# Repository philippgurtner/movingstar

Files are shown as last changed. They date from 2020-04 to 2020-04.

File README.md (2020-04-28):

# Movingstar
SwissSkills Homework 2020

Dieses Projekt dient als Hausaufgabe für die Vorselektion.
Mein persönliches Ziel ist es, die Schweizermesterschaft mit FOSS (Free Open Source Software) zu bestreiten.

## Toolchain
- [KiCad](https://github.com/KiCad) -> ECAD: Schema & Layout
- Python -> Berechnungen: Stern z.B.

## Hardware

### Lichtsensor & ADC
I(10klx) = 1mA
I(100lx) = 23uA
VCC = 5V
=> R=5k
U(10klx) = I*R = 1mA * 5k = 5V
U(100lx) = I*R = 23uA * 5k = 115mV

### I2C Levelshifter
U104 (Bewegung Sensor) wird mit 2.5V - 3V versorgt. Das I2C Signal bei 2.5V Versorgung genügt dem Microcontroller (U102) nicht für ein logisches 1 (0.7 * VCC = 0.7 * 5V = 3.5V)
So muss das Signal geshiftet werden.
Dies geschieht nach [NXP AN10441](https://www.nxp.com/docs/en/application-note/AN10441.pdf) über die beiden Mosfets Q102 & Q103.

### Programmieren
Als Programmierschnittstelle wird die UPDI Schnittstelle von Atmel verwendet. Diese kommt mit einem Pin aus.

### Stromversorgung
Die Stromversorgung wurde über eine USB-C Buchse vorgesehen. Es stehen dann ca. 5V von einem Handelsüblichen Steckernetzteil zur Verfügung.
Imax ~= 30LED * 3Farben * ca. 20mA = 1.8A
Somit sollte die Quelle auf 2A ausgelegt werden um alle LEDs komplett anzusteuern.
Für die Versorgung von U104 Steht ein 3.3V (oder auch 2.5V) Spannungsregler U101 zur Verfügung.
Der Microcontroller U102 wird nicht mit 3.3V Versorgt, da sonst die Taktfrequenz gesenkt werden muss. Dies wurde zum Enwicklungszeitpunkt noch nicht gemacht, um alle Möglichkeiten der LED (WS2812B-2020) Ansteuerung offen zu halten.

### LED Ansteuerung

Als LED Ansteuerung wurden mehrere Möglichkeiten offen gelassen.
- SPI Interface MOSI an PA1 (R105 bestückt)
- I2C Interface SDA an PA1 (R105 bestückt)
- Waveform Generator Output WO3 an PA3 (R106 bestückt)

### Accelerometer U104

Der Beschleunigungssensor wird über I2C über den Levelshifter betrieben. Die Interruptpins können optional verwendet werden.
Die Interrupt Pins müssten auch über einen Levelshifter betrieben werden um eine Korrekte Funktion beim Microcontroller zu erzeugen.

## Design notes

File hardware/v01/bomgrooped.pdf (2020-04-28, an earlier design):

movingstar

## Homework SwissSkills BOM Philipp Gurtner

Source: | https://github.com/philippgurtner/movingstar
Date: | So 12 Apr 2020 15:06:56
Tool: | Eeschema 5.1.5
Component Count: | 84
Reference | Quantity | Value | Footprint
C101 C102 C103 C104 C105 C113 C112 C111 C110 C109 C118 C117 C116 C115 C114 C123 C122 C121 C120 C119 C131 C130 C129 C128 C127 C136 C135 C134 C133 C132 C108 C126 C125 C106 C107 | 35 | 100n | Capacitor_SMD:C_0603_1608Metric
C124 | 1 | 4.7u | Capacitor_SMD:C_0603_1608Metric
D101 D102 D103 D104 D105 D111 D112 D113 D114 D115 D106 D107 D108 D109 D110 D116 D117 D118 D119 D120 D121 D122 D123 D124 D125 D126 D127 D128 D129 D130 | 30 | WS2812B-2020 | ws2812b-2020:WS2812B-2020
J101 | 1 | USB_C_Receptacle_USB2.0 | usbc_molex:USB_C_Molex_fyang05
J103 J102 | 2 | Conn_01x03 | Connector_PinHeader_2.54mm:PinHeader_1x03_P2.54mm_Vertical
Q101 | 1 | TEMT6200FX01 | Resistor_SMD:R_0805_2012Metric
Q102 Q103 | 2 | NMOS_GSD (BSS138P) | Package_TO_SOT_SMD:SOT-23
R101 | 1 | 5k | Resistor_SMD:R_0603_1608Metric
R103 R104 R102 R108 R107 | 5 | 4.7k | Resistor_SMD:R_0603_1608Metric
R106 R105 | 2 | jumper | Resistor_SMD:R_0603_1608Metric
U101 | 1 | LM3480-3.3 | Package_TO_SOT_SMD:SOT-23
U102 | 1 | ATtiny1616-M | Package_DFN_QFN:VQFN-20-1EP_3x3mm_P0.4mm_EP1.7x1.7mm
U103 | 1 | TASTER | taster_smd:TASTER
U104 | 1 | MMA8453Q | Package_DFN_QFN:QFN-16-1EP_3x3mm_P0.5mm_EP1.7x1.7mm

Page 1

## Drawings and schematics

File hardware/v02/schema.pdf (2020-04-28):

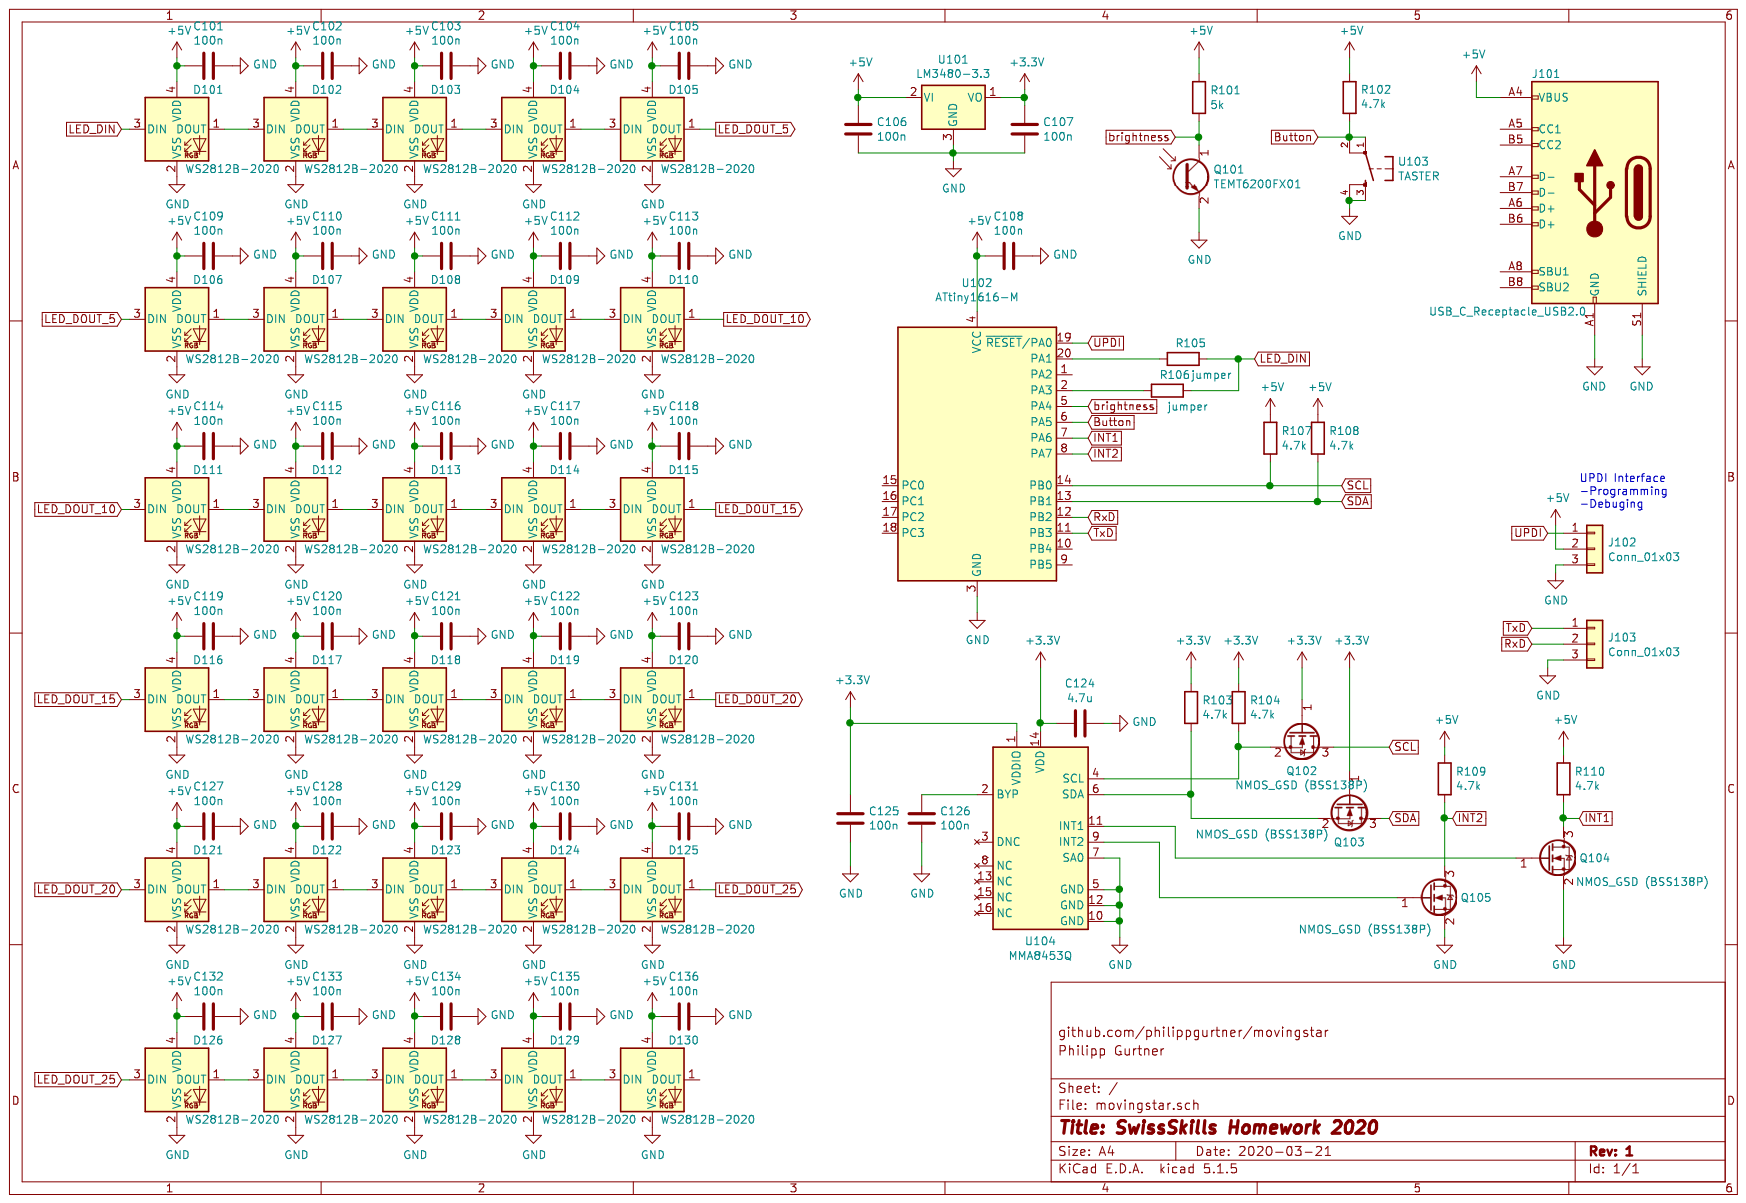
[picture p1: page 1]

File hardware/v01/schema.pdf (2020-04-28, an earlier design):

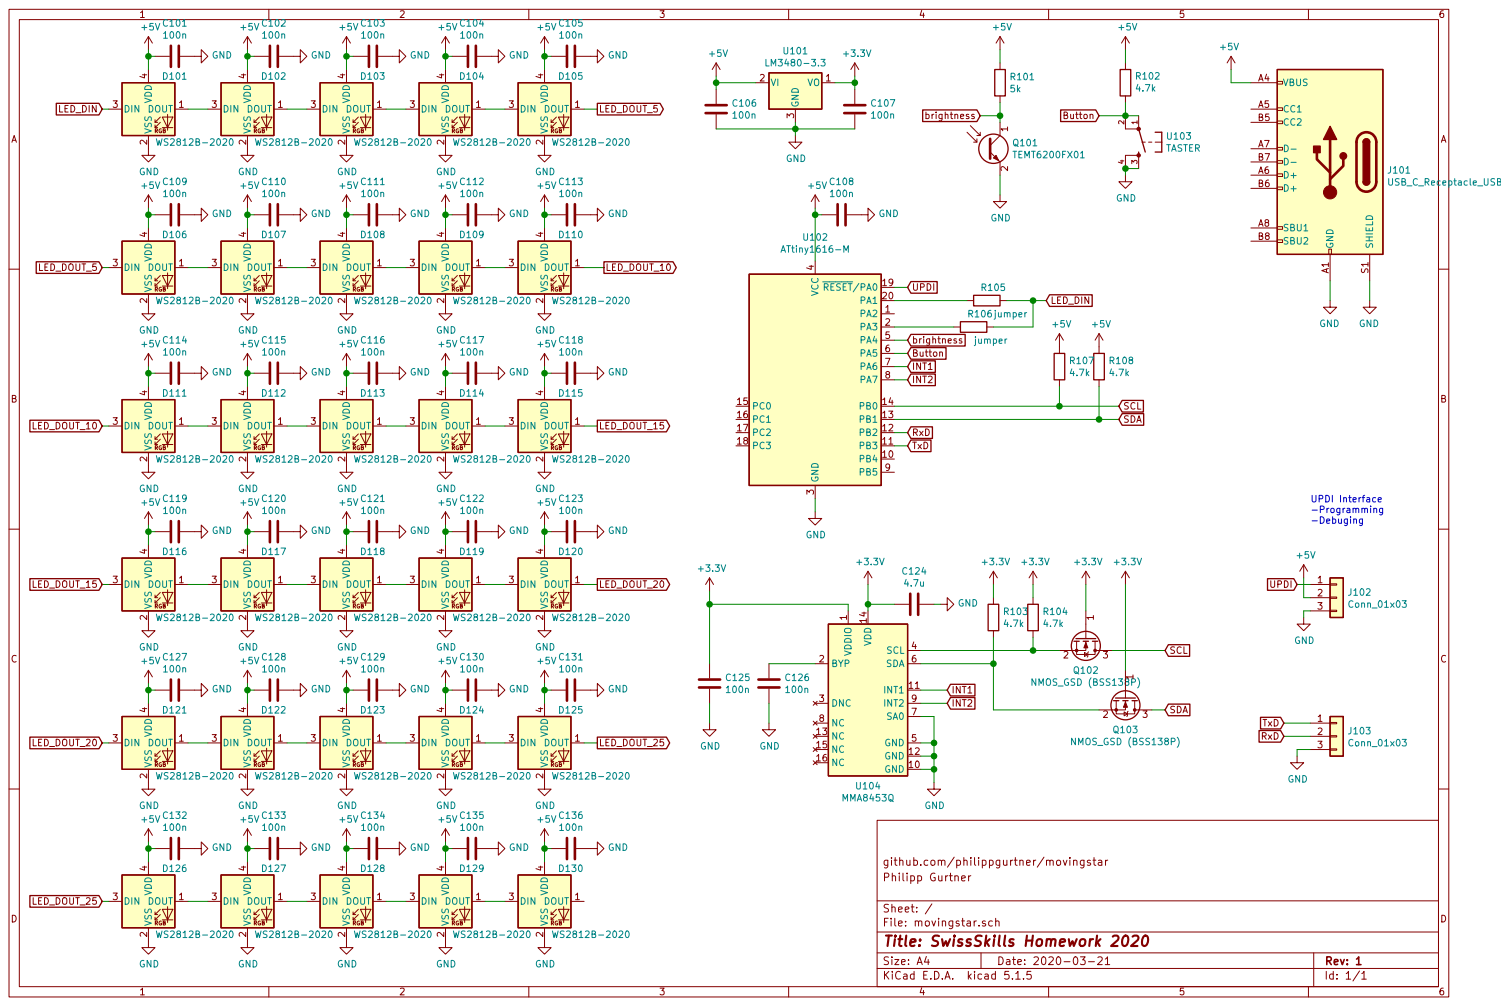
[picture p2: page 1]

1 GND 10 BYP 2 DNC 3 SCL 4 GND 5 SDA 6 SA0 7 NC 8

github.com/philippgurtner/movingstar +5V GND

File: movingstar.sch Sheet: / Philipp Gurtner

Id: 1/1 Title: SwissSkills Homework 2020

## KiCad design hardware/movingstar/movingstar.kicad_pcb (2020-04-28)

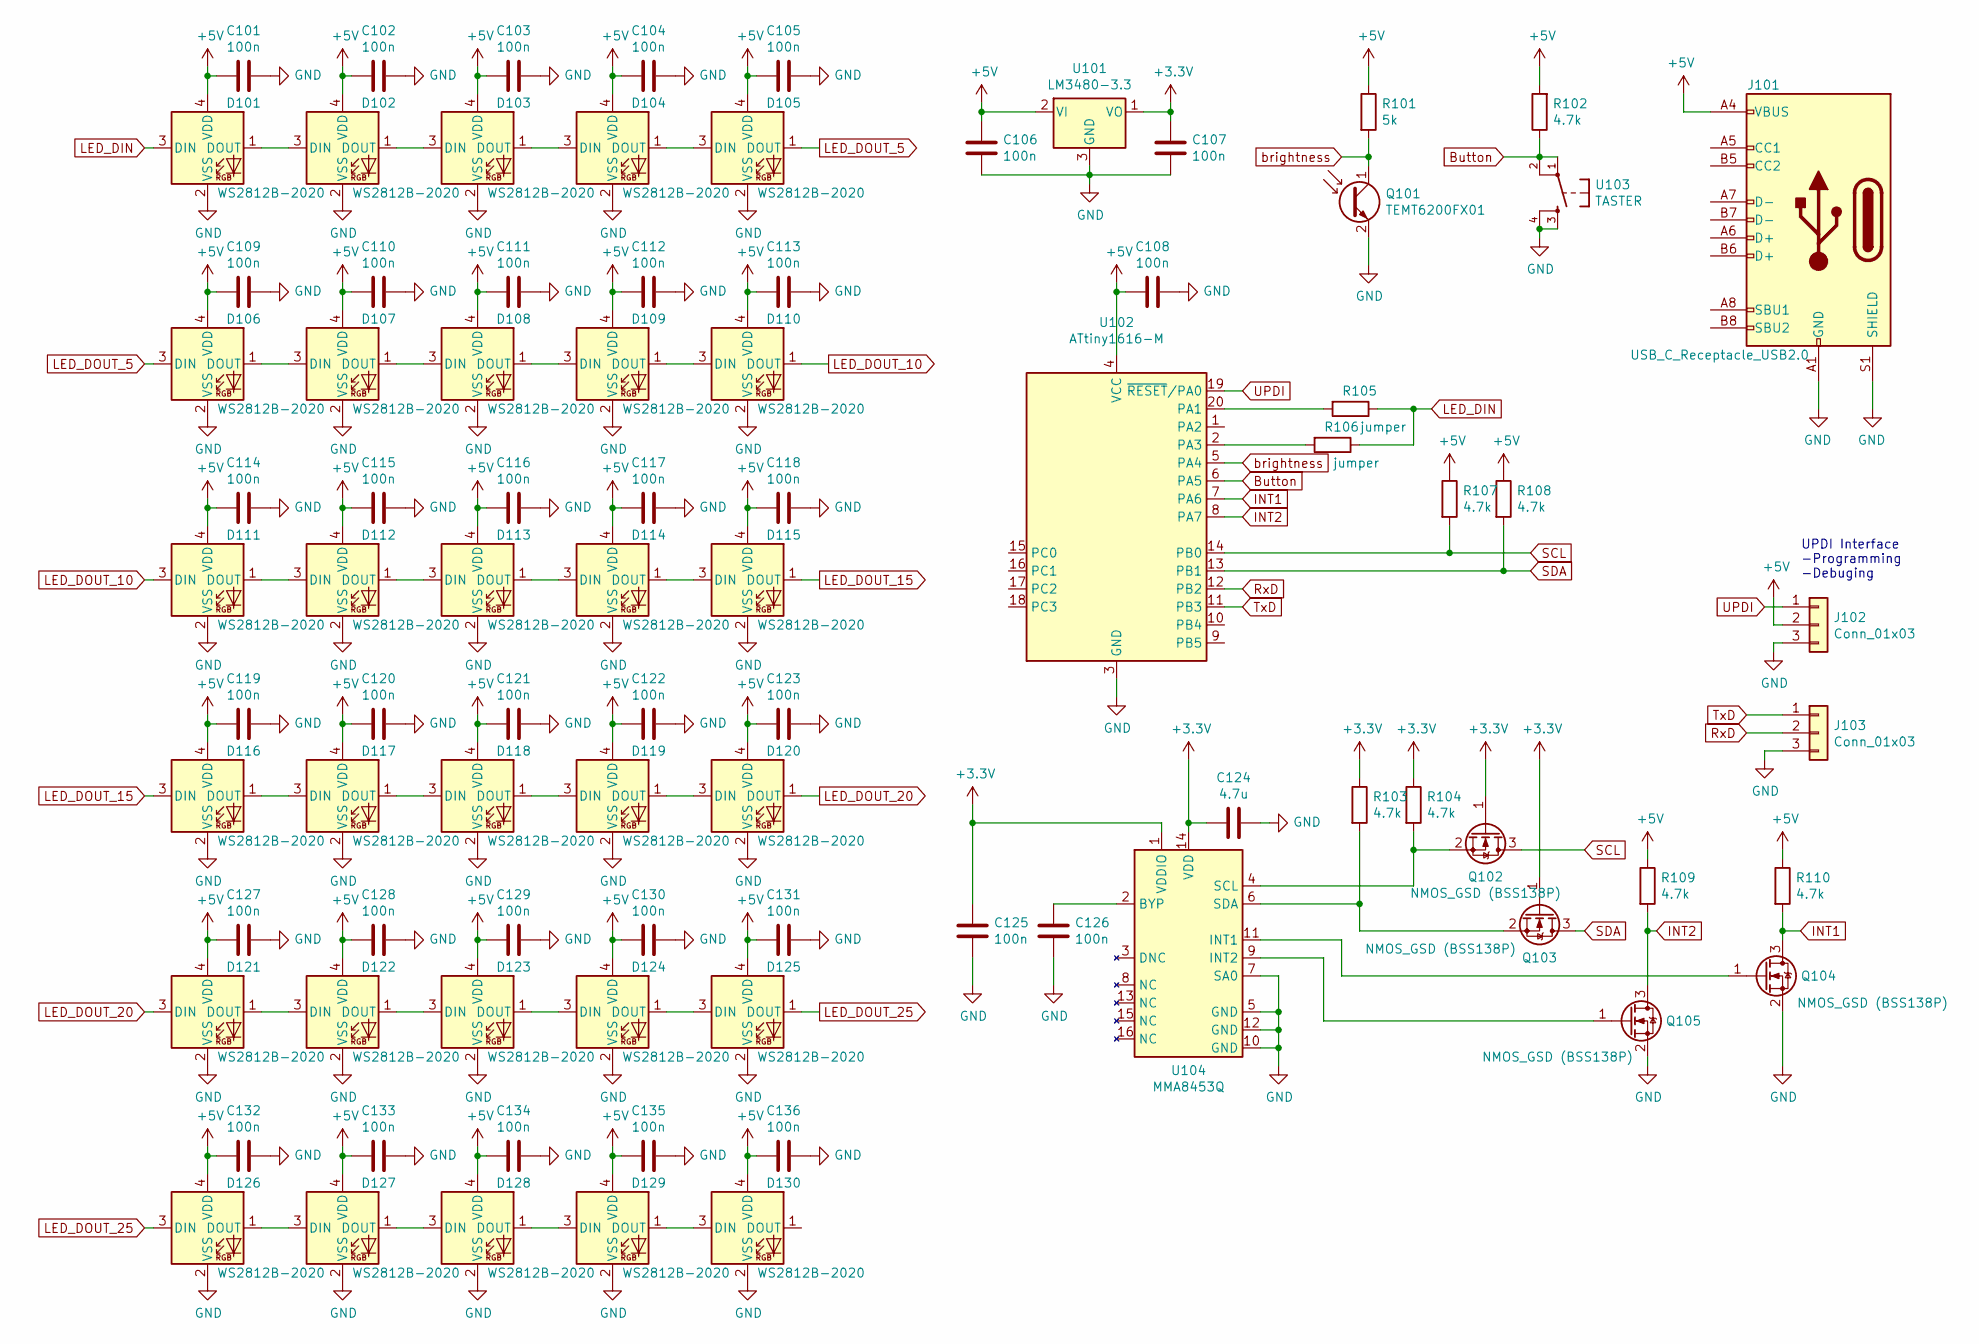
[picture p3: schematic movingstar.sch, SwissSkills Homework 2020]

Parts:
C101, C102, C103, C104, C105, C106, C107, C108, C109, C110, C111, C112, C113, C114, C115, C116, C117, C118, C119, C120, C121, C122, C123, C125, C126, C127, C128, C129, C130, C131, C132, C133, C134, C135, C136: 100n; C_0603_1608Metric
C124: 4.7u; C_0603_1608Metric
D101, D102, D103, D104, D105, D106, D107, D108, D109, D110, D111, D112, D113, D114, D115, D116, D117, D118, D119, D120, D121, D122, D123, D124, D125, D126, D127, D128, D129, D130: WS2812B-2020
J101: USB_C_Receptacle_USB2.0; USB_C_Molex_fyang05
J102, J103: Conn_01x03; PinHeader_1x03_P2.54mm_Vertical
Q101: TEMT6200FX01; R_0805_2012Metric
Q102, Q103, Q104, Q105: NMOS_GSD (BSS138P); SOT-23
R101: 5k; R_0603_1608Metric
R102, R103, R104, R107, R108, R109, R110: 4.7k; R_0603_1608Metric
R105, R106: jumper; R_0603_1608Metric
U101: LM3480-3.3; SOT-23
U102: ATtiny1616-M; VQFN-20-1EP_3x3mm_P0.4mm_EP1.7x1.7mm
U103: TASTER
U104: MMA8453Q; QFN-16-1EP_3x3mm_P0.5mm_EP1.7x1.7mm

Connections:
+3V3: C107.1, C124.2, C125.1, Q102.1 (G), Q103.1 (G), R103.1, R104.1, U101.1 (VO), U104.1 (VDDIO), U104.14 (VDD)
+5V: C101.2, C102.2, C103.2, C104.2, C105.2, C106.1, C108.2, C109.2, C110.2, C111.2, C112.2, C113.2, C114.2, C115.2, C116.2, C117.2, C118.2, C119.2, C120.2, C121.2, C122.2, C123.2, C127.2, C128.2, C129.2, C130.2, C131.2, C132.2, C133.2, C134.2, C135.2, C136.2, D101.4 (VDD), D102.4 (VDD), D103.4 (VDD), D104.4 (VDD), D105.4 (VDD), D106.4 (VDD), D107.4 (VDD), D108.4 (VDD), D109.4 (VDD), D110.4 (VDD), D111.4 (VDD), D112.4 (VDD), D113.4 (VDD), D114.4 (VDD), D115.4 (VDD), D116.4 (VDD), D117.4 (VDD), D118.4 (VDD), D119.4 (VDD), D120.4 (VDD), D121.4 (VDD), D122.4 (VDD), D123.4 (VDD), D124.4 (VDD), D125.4 (VDD), D126.4 (VDD), D127.4 (VDD), D128.4 (VDD), D129.4 (VDD), D130.4 (VDD), J101.A4 (VBUS), J101.A9 (VBUS), J101.B4 (VBUS), J101.B9 (VBUS), J102.2, R101.1, R102.2, R107.1, R108.1, R109.1, R110.1, U101.2 (VI), U102.4 (VCC)
Button: R102.1, U102.6 (PA5), U103.1, U103.2 (P1)
GND: C101.1, C102.1, C103.1, C104.1, C105.1, C106.2, C107.2, C108.1, C109.1, C110.1, C111.1, C112.1, C113.1, C114.1, C115.1, C116.1, C117.1, C118.1, C119.1, C120.1, C121.1, C122.1, C123.1, C124.1, C125.2, C126.2, C127.1, C128.1, C129.1, C130.1, C131.1, C132.1, C133.1, C134.1, C135.1, C136.1, D101.2 (VSS), D102.2 (VSS), D103.2 (VSS), D104.2 (VSS), D105.2 (VSS), D106.2 (VSS), D107.2 (VSS), D108.2 (VSS), D109.2 (VSS), D110.2 (VSS), D111.2 (VSS), D112.2 (VSS), D113.2 (VSS), D114.2 (VSS), D115.2 (VSS), D116.2 (VSS), D117.2 (VSS), D118.2 (VSS), D119.2 (VSS), D120.2 (VSS), D121.2 (VSS), D122.2 (VSS), D123.2 (VSS), D124.2 (VSS), D125.2 (VSS), D126.2 (VSS), D127.2 (VSS), D128.2 (VSS), D129.2 (VSS), D130.2 (VSS), J101.A1 (GND), J101.A12 (GND), J101.B1 (GND), J101.B12 (GND), J101.S1 (SHIELD), J102.3, J103.3, Q101.2 (E), Q104.2 (S), Q105.2 (S), U101.3 (GND), U102.3 (GND), U102.21 (GND), U103.3 (S), U103.4 (S1), U104.5 (GND), U104.7 (SA0), U104.10 (GND), U104.12 (GND)
INT1: Q104.3 (D), R110.2, U102.7 (PA6)
INT2: Q105.3 (D), R109.2, U102.8 (PA7)
LED_DIN: D101.3 (DIN), R105.1, R106.1
LED_DOUT_5: D105.1 (DOUT), D106.3 (DIN)
LED_DOUT_10: D110.1 (DOUT), D111.3 (DIN)
LED_DOUT_15: D115.1 (DOUT), D116.3 (DIN)
LED_DOUT_20: D120.1 (DOUT), D121.3 (DIN)
LED_DOUT_25: D125.1 (DOUT), D126.3 (DIN)
unnamed: C126.1, U104.2 (BYP)
unnamed: D101.1 (DOUT), D102.3 (DIN)
unnamed: D102.1 (DOUT), D103.3 (DIN)
unnamed: D103.1 (DOUT), D104.3 (DIN)
unnamed: D104.1 (DOUT), D105.3 (DIN)
unnamed: D106.1 (DOUT), D107.3 (DIN)
unnamed: D107.1 (DOUT), D108.3 (DIN)
unnamed: D108.1 (DOUT), D109.3 (DIN)
unnamed: D109.1 (DOUT), D110.3 (DIN)
unnamed: D111.1 (DOUT), D112.3 (DIN)
unnamed: D112.1 (DOUT), D113.3 (DIN)
unnamed: D113.1 (DOUT), D114.3 (DIN)
unnamed: D114.1 (DOUT), D115.3 (DIN)
unnamed: D116.1 (DOUT), D117.3 (DIN)
unnamed: D117.1 (DOUT), D118.3 (DIN)
unnamed: D118.1 (DOUT), D119.3 (DIN)
unnamed: D119.1 (DOUT), D120.3 (DIN)
unnamed: D121.1 (DOUT), D122.3 (DIN)
unnamed: D122.1 (DOUT), D123.3 (DIN)
unnamed: D123.1 (DOUT), D124.3 (DIN)
unnamed: D124.1 (DOUT), D125.3 (DIN)
unnamed: D126.1 (DOUT), D127.3 (DIN)
unnamed: D127.1 (DOUT), D128.3 (DIN)
unnamed: D128.1 (DOUT), D129.3 (DIN)
unnamed: D129.1 (DOUT), D130.3 (DIN)
unnamed: Q102.2 (S), R104.2, U104.4 (SCL)
unnamed: Q103.2 (S), R103.2, U104.6 (SDA)
unnamed: Q104.1 (G), U104.11 (INT1)
unnamed: Q105.1 (G), U104.9 (INT2)
unnamed: R105.2, U102.20 (PA1)
unnamed: R106.2, U102.2 (PA3)
RxD: J103.2, U102.12 (PB2)
SCL: Q102.3 (D), R107.2, U102.14 (PB0)
SDA: Q103.3 (D), R108.2, U102.13 (PB1)
TxD: J103.1, U102.11 (PB3)
UPDI: J102.1, U102.19 (~RESET~/PA0)
brightness: Q101.1 (C), R101.2, U102.5 (PA4)

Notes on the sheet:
UPDI Interface -Programming -Debuging

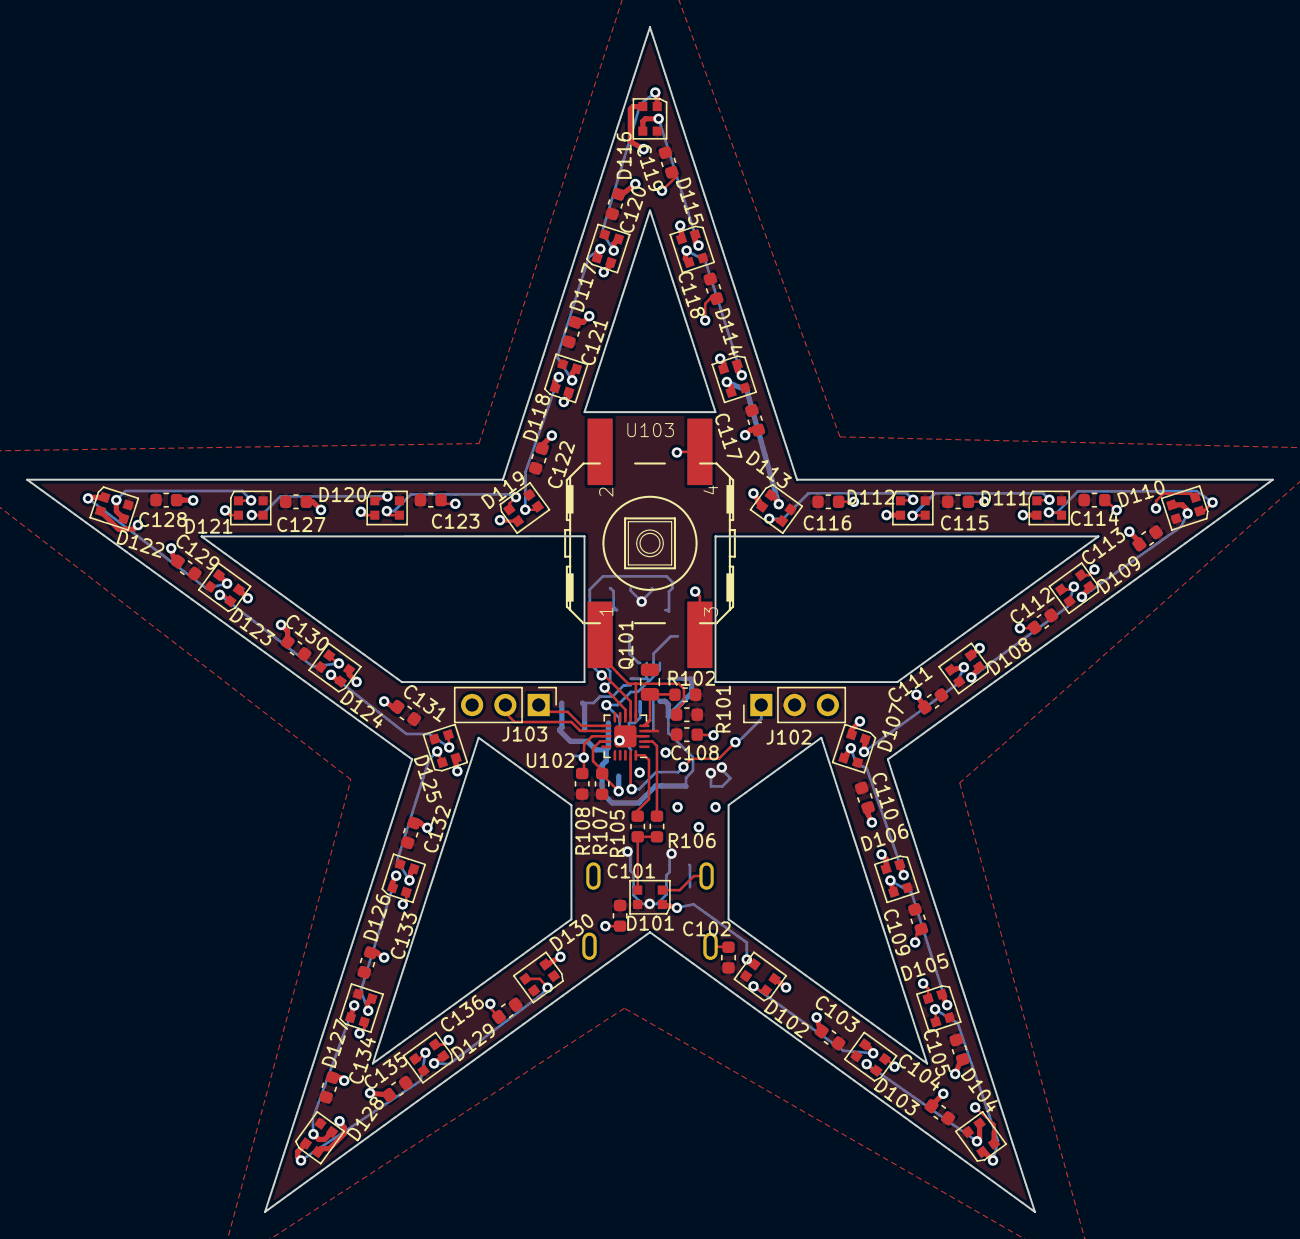
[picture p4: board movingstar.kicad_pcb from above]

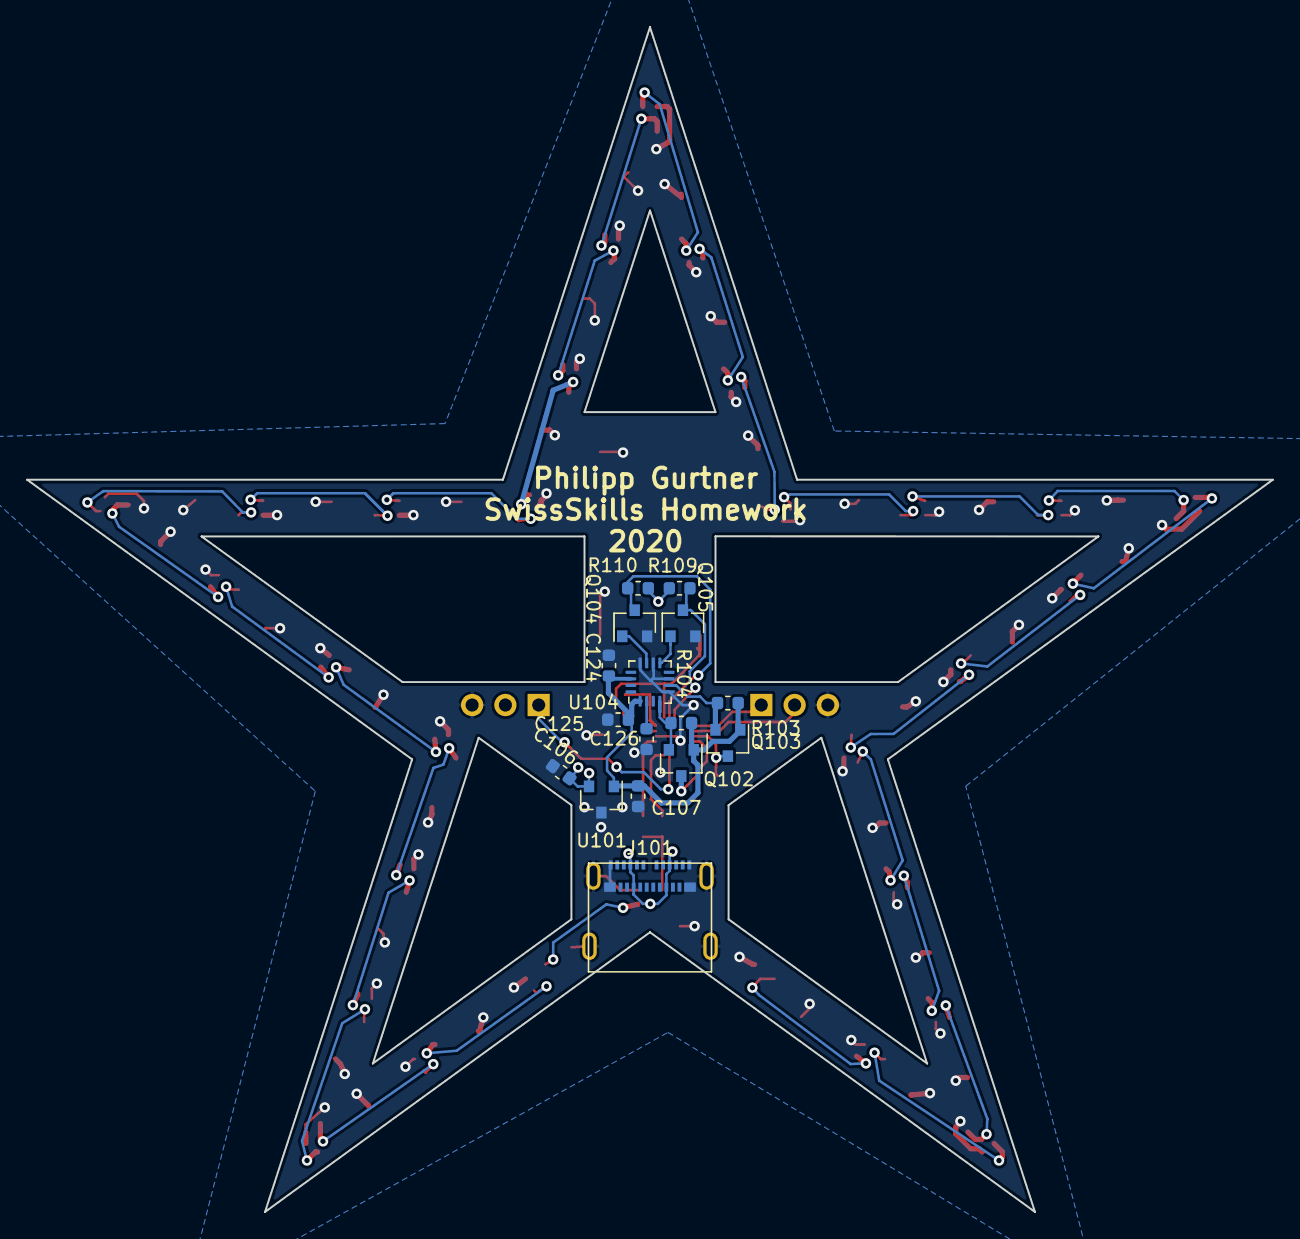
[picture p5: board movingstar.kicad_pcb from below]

Board: 2 copper layers, 95.1 x 90.4 mm, 88 parts (16 on the bottom side), 49 nets.
